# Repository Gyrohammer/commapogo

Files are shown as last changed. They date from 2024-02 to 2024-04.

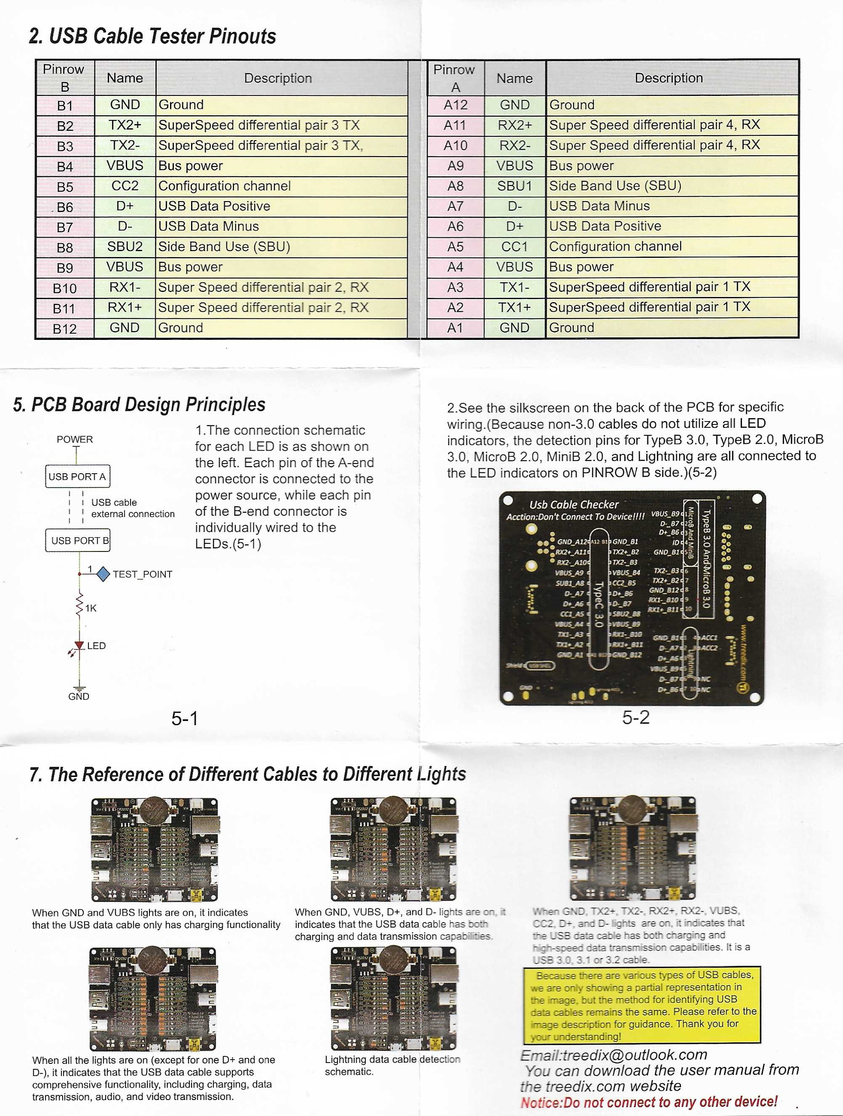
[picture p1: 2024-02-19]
testing_equipment/cable_tester/manual2.jpg

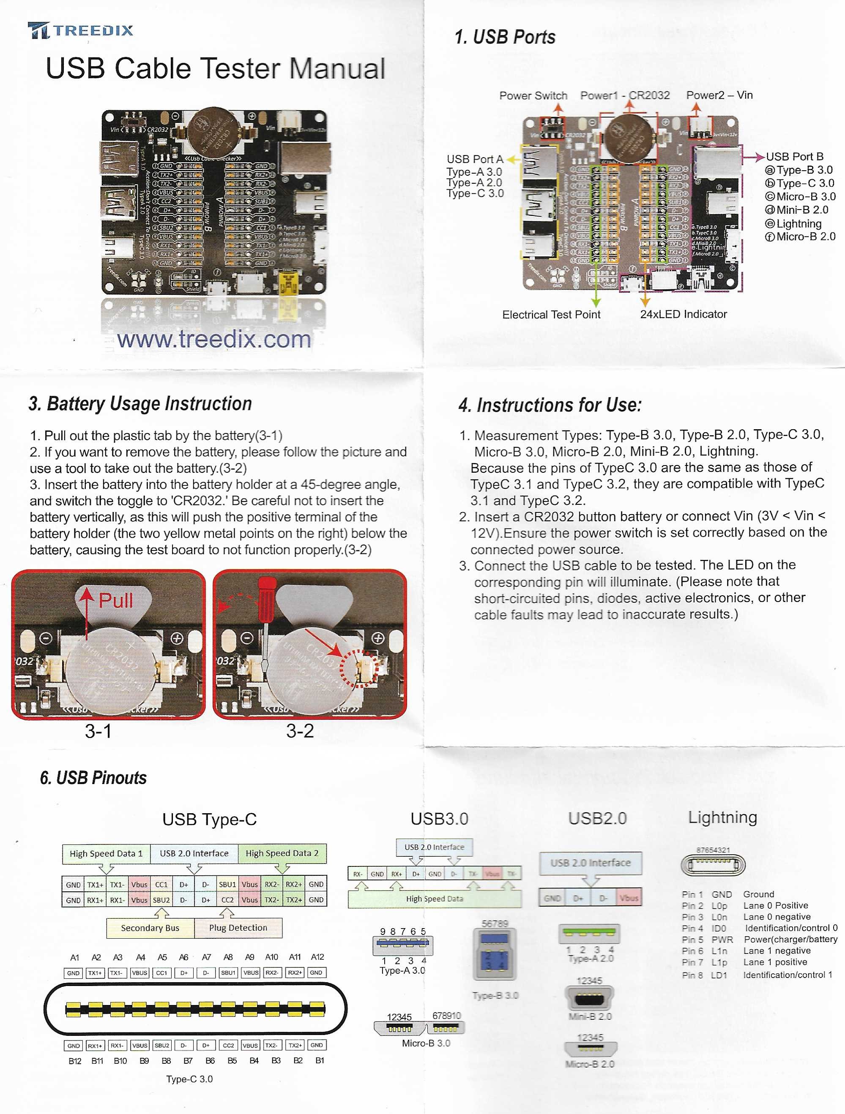
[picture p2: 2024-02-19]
testing_equipment/cable_tester/manual1.jpg

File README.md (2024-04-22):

# CommaPOGO
I recently have come across a project for the Comma3X that utilizes pogo pins for the quick disconnect of a comma3x. This is my attempt to create an open source alternative to that mount that is DIY and 3D printable. I was inspired after seeing the mount that @cloudj0816 made in the [OpenPilot community discord](https://discord.com/invite/avCJxEX). All credit goes to him for this initial idea! If you'd like to purchase one of his connectors (full CNC metal), you can find the wait list in the #hw-unofficial channel. 

## Goals:
- Inexpensive
- Open Source
- 3D Printed
- ~~Angle adjustment (for imperfect mounting positions)~~
    - This is more of a future goal. I'm first going to focus on getting the static mount correct.

## Progress Tracking
### Parts
Preliminary BOM: 
| Colloqiual Name| Part No. | Quantity | 
| --- | --- | --- |
| Pogo Pin  | ~~2906-4-15-20-75-14-11-0~~  | ~~14~~ |
| USB-C Connector | ~~HC005-1A1H1A103-0HR~~ | 2 |
| ASA Filament | n/a | <100g |
| K&J Magnets | D83-N52 | 4 |
|3M Adhesive | 3M™ VHB™ Tape 5952 | ~100mm<sup>2</sup> (~1.5in<sup>2</sup>)|

- [x] Pogo Pins
- [x] USB-C Connector
- [x] Magnets
- [x] Adhesive
#
### Board Development
- [x] General layout
- [x] Trace routing
- [x] Trace power calculations - Data analysis pending (2/15/24)
#### MKI Development
- [x] Initial refinement (MKI)
- [x] Finalization
- [x] Ordered 
- [x] Testing - Failed
- [x] Troubleshooting/diagnosis begins for MKI
- [x] Results finalized, head into next revision.  
#### MKII Development
- [x] Secondary Refinement (MKII)
- [x] Ordered
- [x] Testing - Failed
- [x] Troubleshooting/diagnosis begins for MKII
- [x] Project frozen.
- [ ] Results finalized, head into next (final) revision.
#### MKIII Development
- [ ] Tertiary Refinement (MKIII)
- [ ] Ordered
- [ ] Testing
- [ ] Troubleshooting/diagnosis begins for MKIII
- [ ] Results finalized.

#
### C3X Windshield Mount
- [x] PCB imported and modeled.
- [x] Male mount modeled
- [x] Female mount modeled
- [x] Mock-up mount printed.
- [x] Mount refinement
- [x] Test-bed mounts printed
- [x] Test-beds tested
- [x] 'Gravimatrix' mock-up printed
- [x] Project frozen.
- [ ] 'Gravimatrix' refinement - Minor adjustments being made
- [ ] Preliminary testing
- [ ] Production unit trials
#
### Field Testing
- [ ] Endurance testing (50 hours usage)
- [ ] Vibration testing
- [ ] Heat testing (7 day constant connectivity)
#
## Specifications Pertaining to the Project
- Comma3X Weight: 311g (11oz)
- Power Usage: See the [summary spreadsheet](/power_data/summary.xlsx) for this data.
#
## Separate Updates

### March 10th, 2024
I've gotten the first hand-built boards put together and making a solid connection! The most likely candidate for the mounting system will be the Gravimatrix design, as that is the most solid. But as of 3/10/24 I have a working prototype! Soldering USB-C connectors by hand is extremely difficult, who'da thunk it?

These connectors will likely be soldered on from the manufacturer going forward, this will ensure consistency and quality at the cost of a few cents per board. A compromise I am more than willing to make.

### March 19th, 2024

PCB no worky! I believe I have some crosstalk/interference throughout the coupler. I'll be re-assessing and redesigning the PCB to hopefully counteract this and get a working connection.

### March 21st, 2024

This weekend I'll be using an oscilloscope to check signal integrity. Hopefully its simple as that, and adding a ground plane(s) will solve it. I had no idea what a ground-plane was until I asked for ideas/advice on the electrical engineering stack exchange. [Heres the thread where that was suggested!](https://electronics.stackexchange.com/questions/706633/usb-c-pogo-pin-coupler-troubleshooting).

### April 10th, 2024

Oscilloscope readings showed little to no interference. Messages were coming and going normally, with solid definition. The second PCB design has run into the same error, in the same way. I will be doing some more testing including soldering wires directly from pad-to-pad in an attempt to isolate this to one component. If that doesnt work, I'll be doing one final re-design before putting this project on hold for a while.

### April 18th, 2024
I finally got around to wiring the pads directly to one another for testing! Bad news is that it still doesnt work. I'm unsure, at this point, why this board doesnt work correctly. I feel as if I'm getting some sort of cross-talk between the connections. I'll be tring one more configuration, flipped, to see if that yields any other results. If this doesnt work then I have a backup plan which involves some consumer-hardware and a 3D printed case to house it. I'm hoping this custom solution works, as I put a lot of time into it, but if not then it is what it is. I should've gotten an EE degree, physics is useless here! Actually it was useful for the magnet force calculations.

### April 22nd, 2024
Unfortunately it seems that I've hit the limit of my knowledge/ability with this project. I cannot get the communication to work correctly across the interlink. I have already spend about $400 in material on this project, putting together another PCB for order would only add to that and would likely not work. Not to mention the hours spent testing and designing the mounts/PCB revisions. This was still an excellent journey to go on! Maybe one day I'll revisit it. This repo does contain some useful info, though, such as power statistics and the weight of the unit, hopefully that will be useful to someone should they stumble across this.

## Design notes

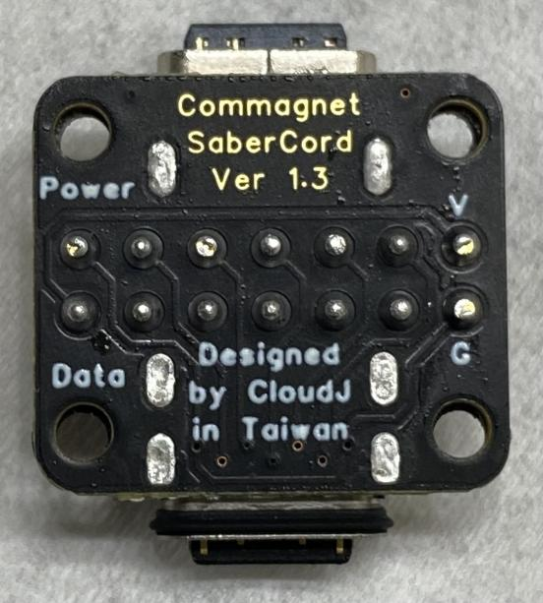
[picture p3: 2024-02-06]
sabercord_reference/PCB_Layout.webp

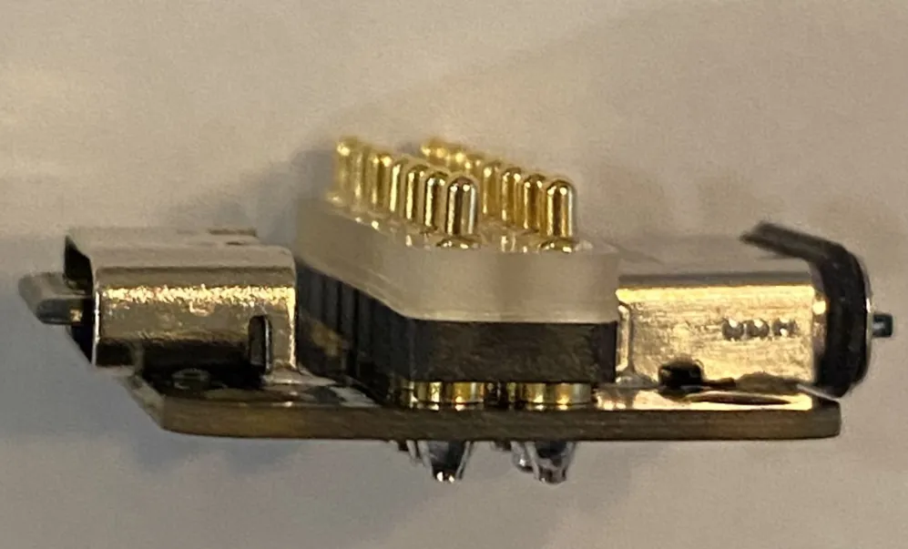
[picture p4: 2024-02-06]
sabercord_reference/side_shot.webp

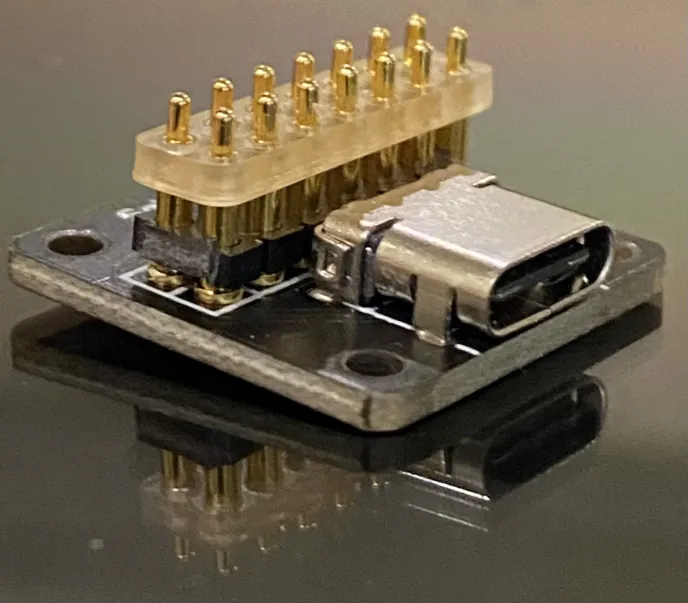
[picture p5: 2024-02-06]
sabercord_reference/aboce_shot.webp

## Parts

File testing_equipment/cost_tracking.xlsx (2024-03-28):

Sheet: Project Overall
Item | Description | Cost | Date | Total | Breakeven Units | Project Length (days) | Cost/Day
Digikey 1 | Pogo pins and USB-C connectors | $33.90 | 2024-02-15 | $342.71 | 7 | 41 | $8.36
K&J Magnets | Misc magnet testing | $55.00 | 2024-02-15
PCBWay 1 | Initial pcb order | $19.24 | 2024-02-17
PCBWay 2 | Second pcb order assembled | $42.80 | 2024-03-06
JLCPCB 1 | First assembled order, failed in prod | $5.15 | 2024-03-07
JLCPCB 2 | Second assembled order, useless | $50.25 | 2024-03-11
Digikey 2 | Pogo pins and pogo pins | $59.70 | 2024-03-12
JLCPCB 3 | Third assembled order, pending | $54.49 | 2024-03-27
K&J Magnets | Final magnet testing | $22.18 | 2024-03-27

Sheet: Per Unit
Component | Price/unit | Quantity | Total | Raw Cost
Pogo Pins | $0.64 | 14 | $8.97 | $40.01
PCB | $12.00 | 2 | $24.00
Magnets | $1.71 | 4 | $6.84
ASA | $25.00 | 0.008 | $0.20

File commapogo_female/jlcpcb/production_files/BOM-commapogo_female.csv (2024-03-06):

Comment | Designator | Footprint | LCSC
Conn_02x12_Row_Letter_Last | J2 | USB-C-SMD_HC005-1A1H1A103-0HR | C2894904

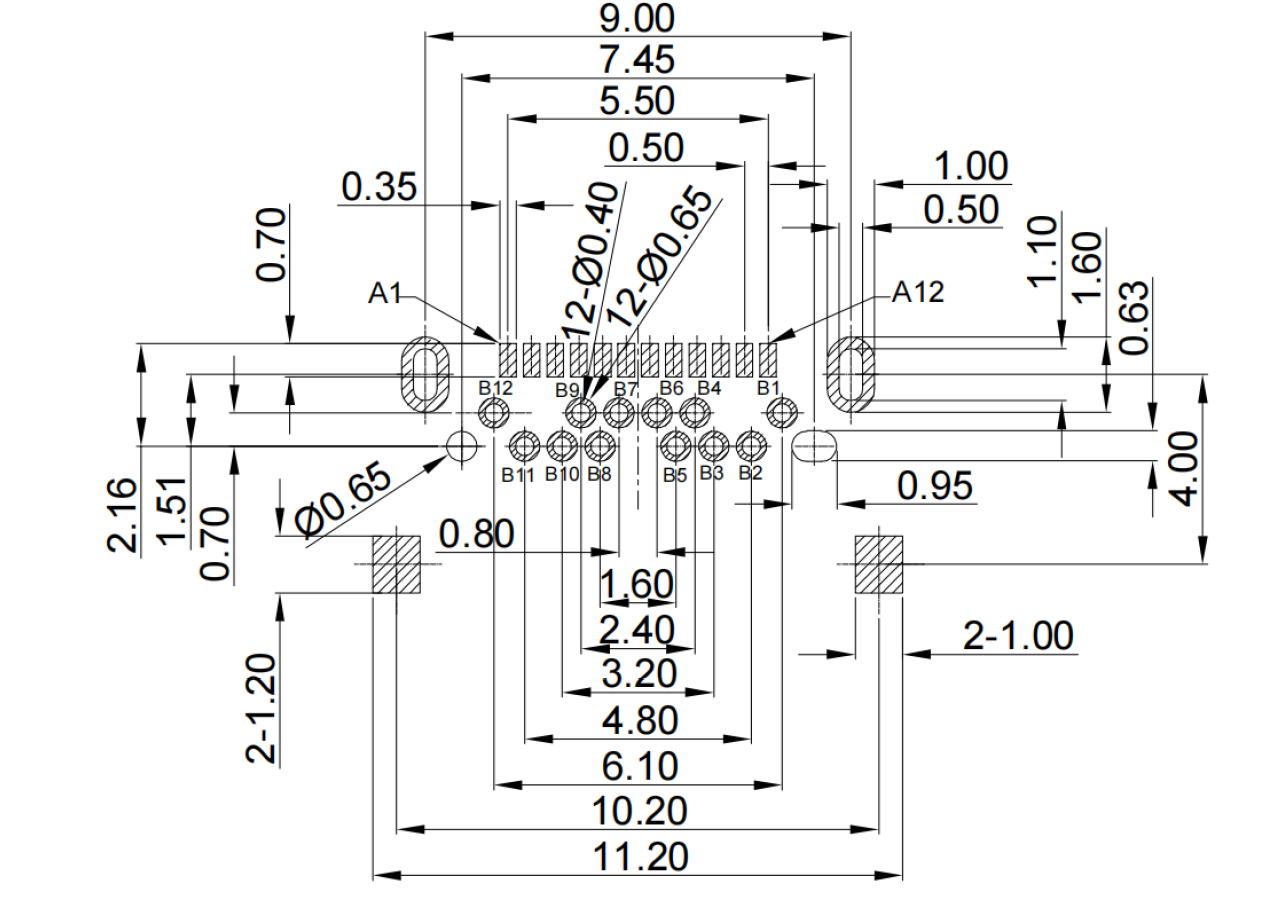
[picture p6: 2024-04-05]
component_data/usb_connector/GT-USB-7001C/GT-USB-7001C.png

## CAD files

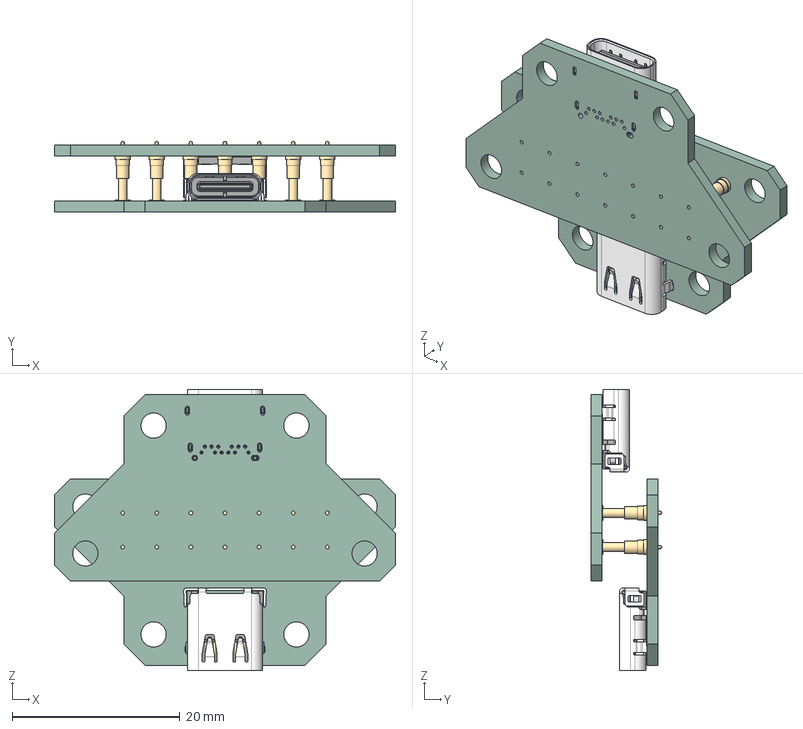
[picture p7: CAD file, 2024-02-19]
3d files/baseline_model/baseline_PCB.step
40.6 x 8.41 x 33.5 mm
PogoPads x 14
SaberCord_Copy_Male PCB x 2

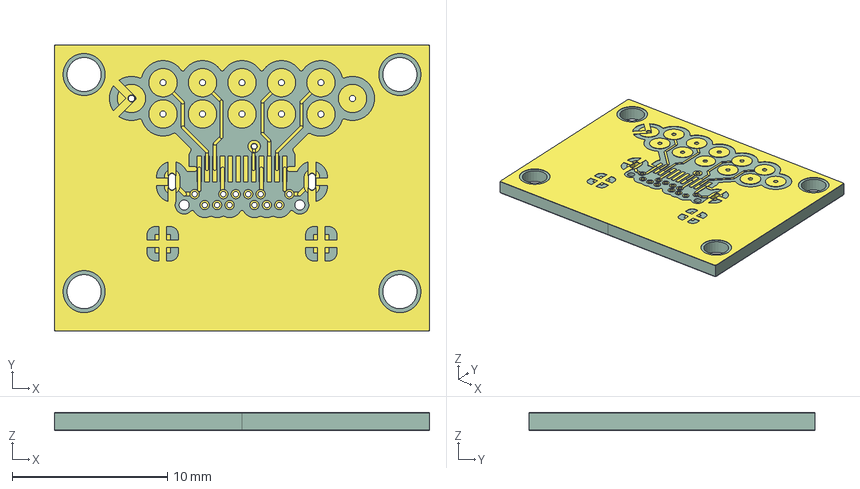
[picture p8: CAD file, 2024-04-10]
3d files/commaPOGO.step
24.1 x 18.4 x 1.16 mm
commapogo_male_track_1
commapogo_male_track_2
commapogo_male_track_3
commapogo_male_track_4
commapogo_male_track_5
commapogo_male_track_6
commapogo_male_track_7
commapogo_male_track_8
commapogo_male_track_9
commapogo_male_track_10
commapogo_male_track_11
commapogo_male_track_12
commapogo_male_track_13
commapogo_male_track_14
commapogo_male_track_15
commapogo_male_track_16
commapogo_male_track_17
commapogo_male_track_18
commapogo_male_track_19
commapogo_male_track_20
commapogo_male_track_21
commapogo_male_track_22
commapogo_male_track_23
commapogo_male_track_24
commapogo_male_track_25
commapogo_male_track_26
commapogo_male_track_27
commapogo_male_track_28
commapogo_male_track_29
commapogo_male_track_30
commapogo_male_track_31
commapogo_male_track_32
commapogo_male_track_33
commapogo_male_zone_1
commapogo_male_zone_2
commapogo_male_pad_1
commapogo_male_pad_2
commapogo_male_pad_3
commapogo_male_pad_4
commapogo_male_pad_5
commapogo_male_pad_6
commapogo_male_pad_7
commapogo_male_pad_8
commapogo_male_pad_9
commapogo_male_pad_10
commapogo_male_pad_11
commapogo_male_pad_12
commapogo_male_pad_13
commapogo_male_pad_14
commapogo_male_pad_15
commapogo_male_pad_16
commapogo_male_pad_17
commapogo_male_pad_18
commapogo_male_pad_19
commapogo_male_pad_20
commapogo_male_pad_21
commapogo_male_pad_22
commapogo_male_pad_23
commapogo_male_pad_24
commapogo_male_pad_25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

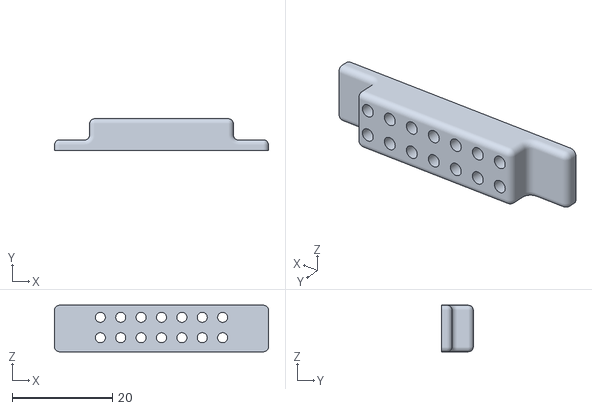
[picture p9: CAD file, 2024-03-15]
3d files/pogo_jigs/pogo_pin_jig_2p000_thick.stl
42.7 x 6.30 x 9.28

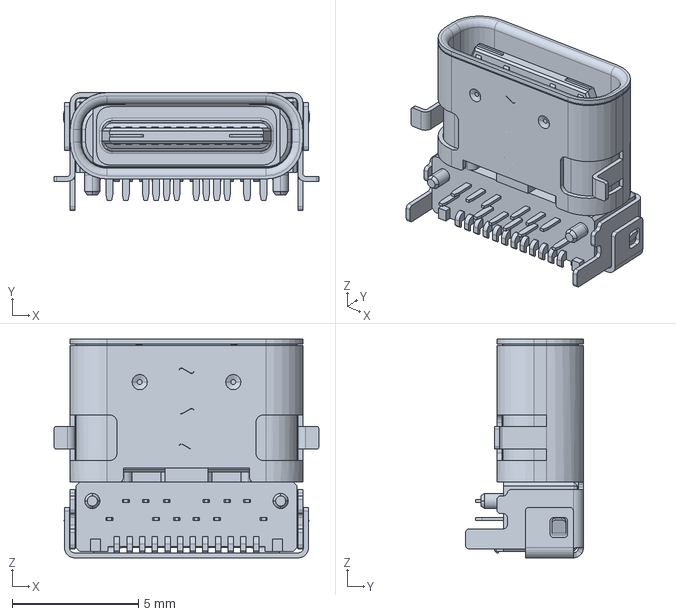
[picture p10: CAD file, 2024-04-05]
3d files/pre-fab_parts/GT-USB-7001C.stp
10.5 x 4.66 x 8.65 mm

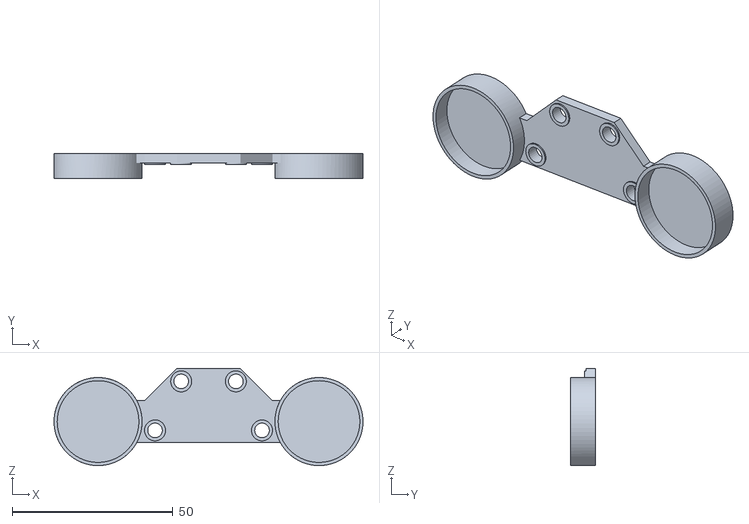
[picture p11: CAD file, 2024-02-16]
3d files/prototype_Gravimatrix/gravimatrix_d73/windshield_side.stl
96.1 x 7.66 x 30.2

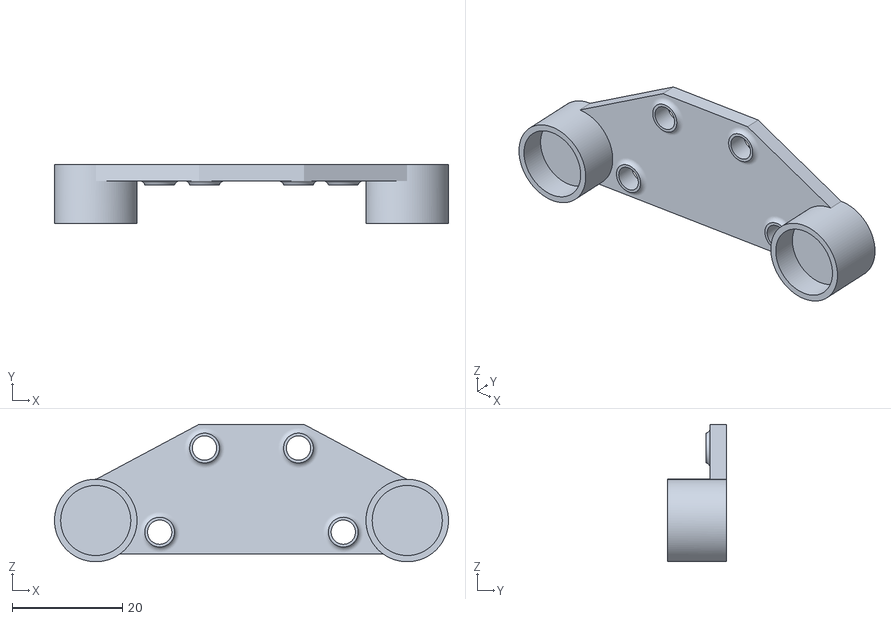
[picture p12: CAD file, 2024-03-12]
3d files/prototype_Gravimatrix/gravimatrix_d83/windshield_side_v2.stl
71.4 x 10.8 x 24.9

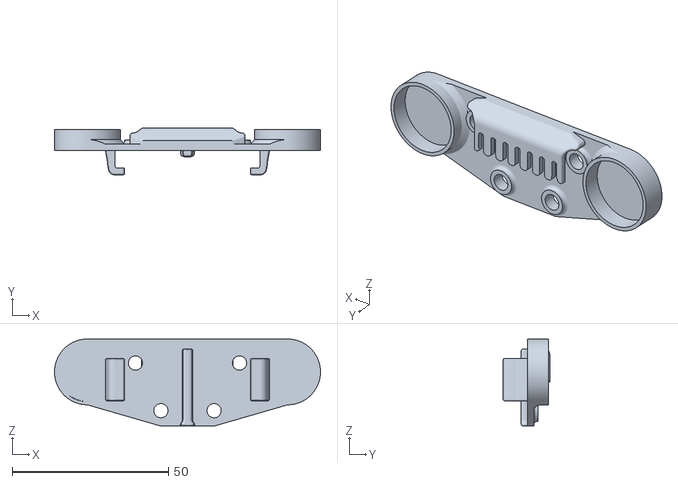
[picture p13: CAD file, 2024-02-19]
3d files/prototype_Gravimatrix/gravimatrix_dc3/unit_side.stl
85.1 x 15.0 x 27.8

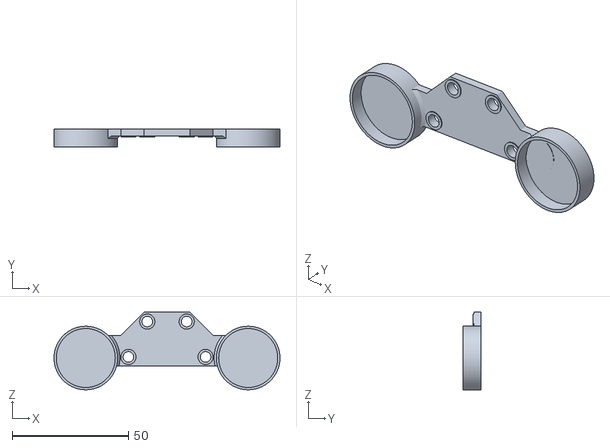
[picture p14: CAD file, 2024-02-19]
3d files/prototype_Gravimatrix/gravimatrix_dx03/windshield_side.stl
97.4 x 7.65 x 33.4

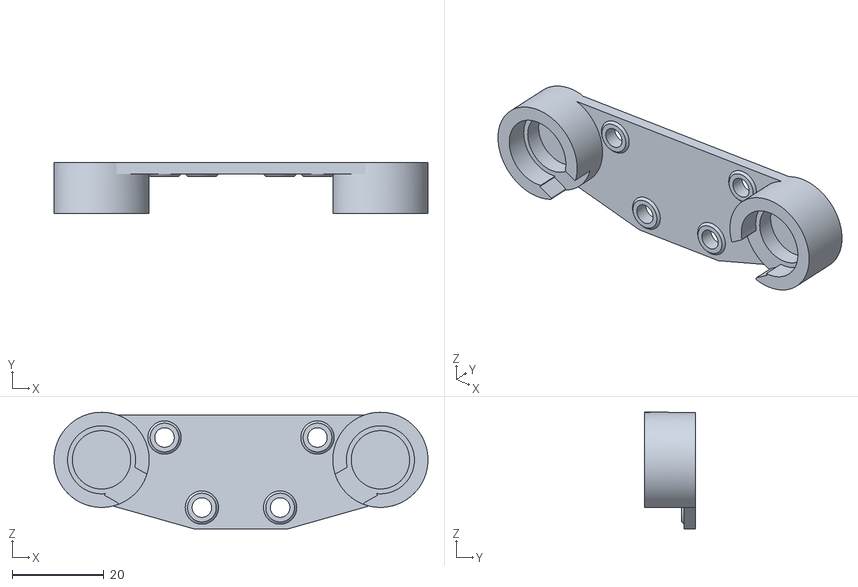
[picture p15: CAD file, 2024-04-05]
3d files/prototype_Gravimatrix/windshield_side_slotted.stl
81.4 x 11.0 x 25.3

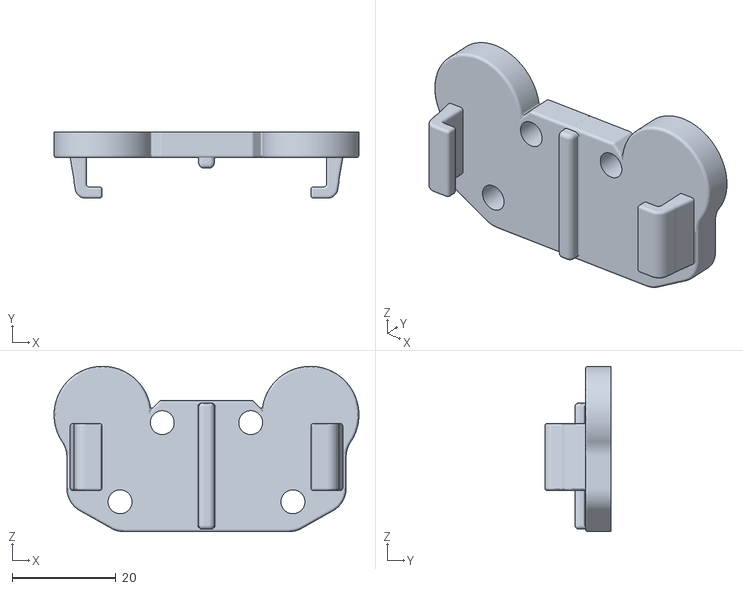
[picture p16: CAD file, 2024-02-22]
3d files/prototype_polaron/unit mount.stl
58.7 x 12.8 x 31.8

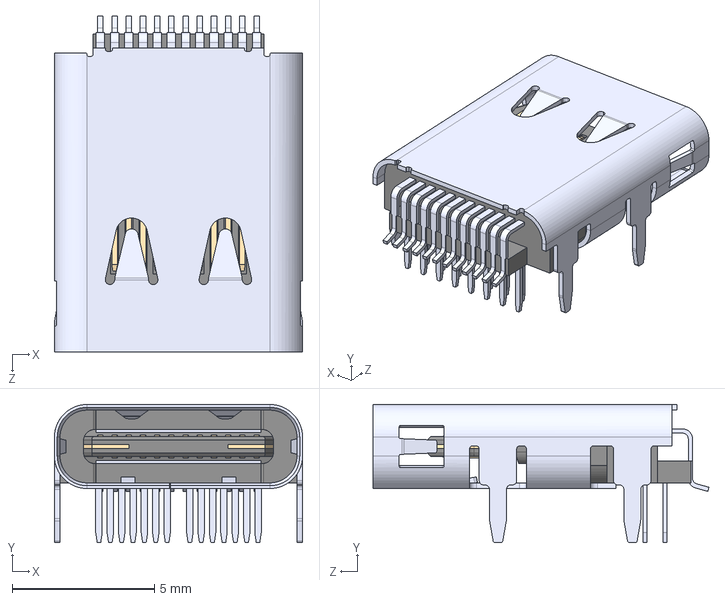
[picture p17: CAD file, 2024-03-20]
component_data/usb_connector/SS_52400_003/SS-52400-003.step
8.74 x 4.86 x 11.8 mm

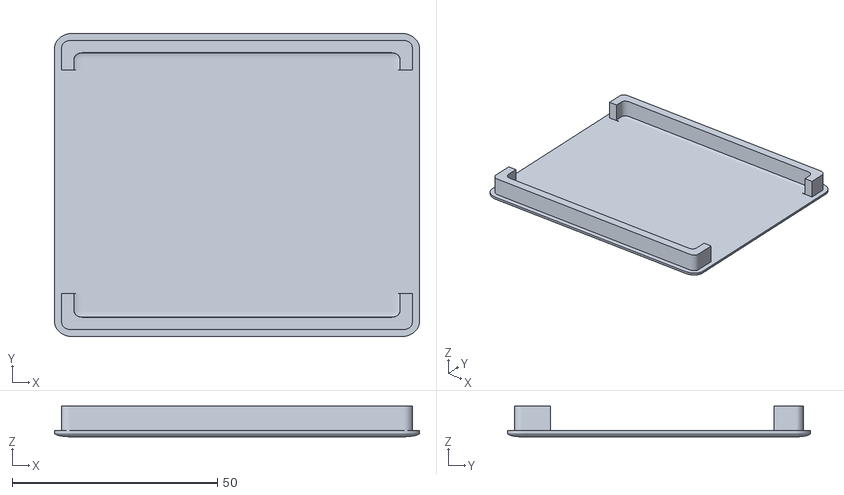
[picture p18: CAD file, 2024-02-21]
testing_equipment/cable_tester/usb3cablecheckdeckel.stl
89.0 x 74.0 x 7.50

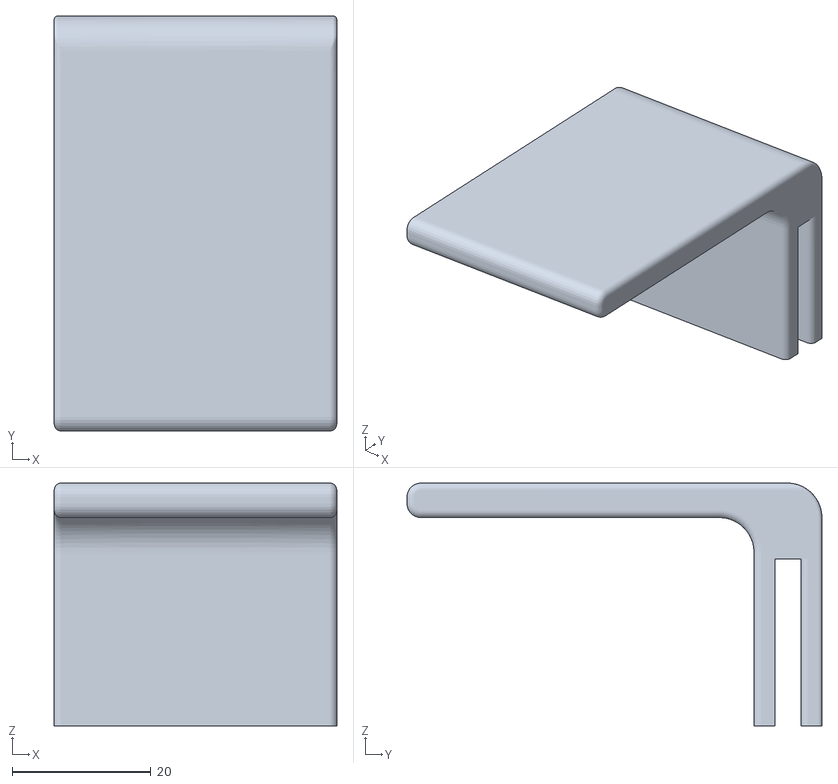
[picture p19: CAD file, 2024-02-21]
testing_equipment/mount_shock_test.stl
40.7 x 59.8 x 35.0

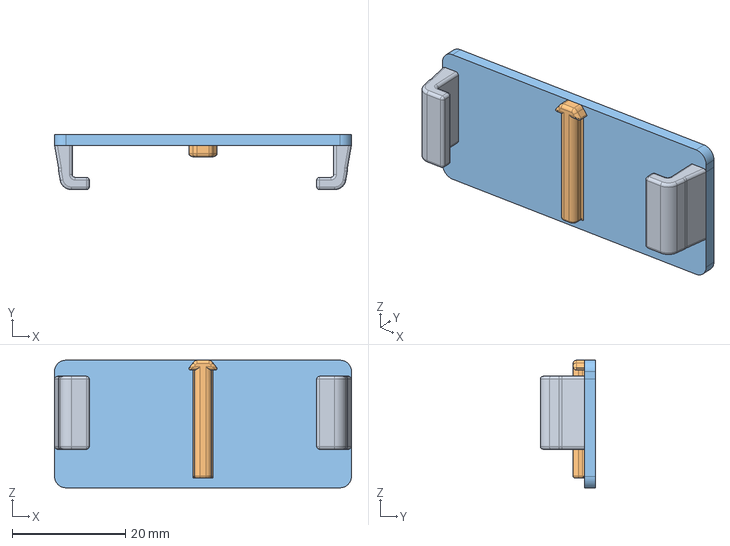
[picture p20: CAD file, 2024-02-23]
3d files/comma3x_windshield_mount.step
52.5 x 9.80 x 22.6 mm

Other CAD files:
3d files/pogo_jigs/pogo_pin_jig_1p800_thick.stl
3d files/pre-fab_parts/2906-4-15-20-75-14-11-0.step
3d files/prototype_Gravimatrix/gravimatrix_d73/unit_side.stl
3d files/baseline_model/baseline_PCB.dwg
3d files/baseline_model/baseline_pcb_only.f3z
3d files/comma3x_windshield_mount.dwg
3d files/comma3x_windshield_mount.f3d
3d files/pogo_jigs/pogo_pin_jig_0p07.stl
3d files/pogo_jigs/pogo_pin_jig_0p125.stl
3d files/pogo_jigs/pogo_pin_jig_1p250.stl
3d files/pogo_jigs/pogo_pin_jig_1p350.stl
3d files/pogo_jigs/pogo_pin_jig_1p400.stl
3d files/pogo_jigs/pogo_pin_jig_1p400_framed.stl
3d files/pogo_jigs/pogo_pin_jig_1p400_thick.stl
3d files/pogo_jigs/pogo_pin_jig_1p400_thin.stl
3d files/pogo_jigs/pogo_pin_jig_1p50offset.stl
3d files/pogo_jigs/pogo_pin_jig_1p50offset_thick.stl
3d files/pogo_jigs/pogo_pin_jig_1p600_thick.stl
3d files/pogo_jigs/pogo_pin_jig_1p640_thick.step
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

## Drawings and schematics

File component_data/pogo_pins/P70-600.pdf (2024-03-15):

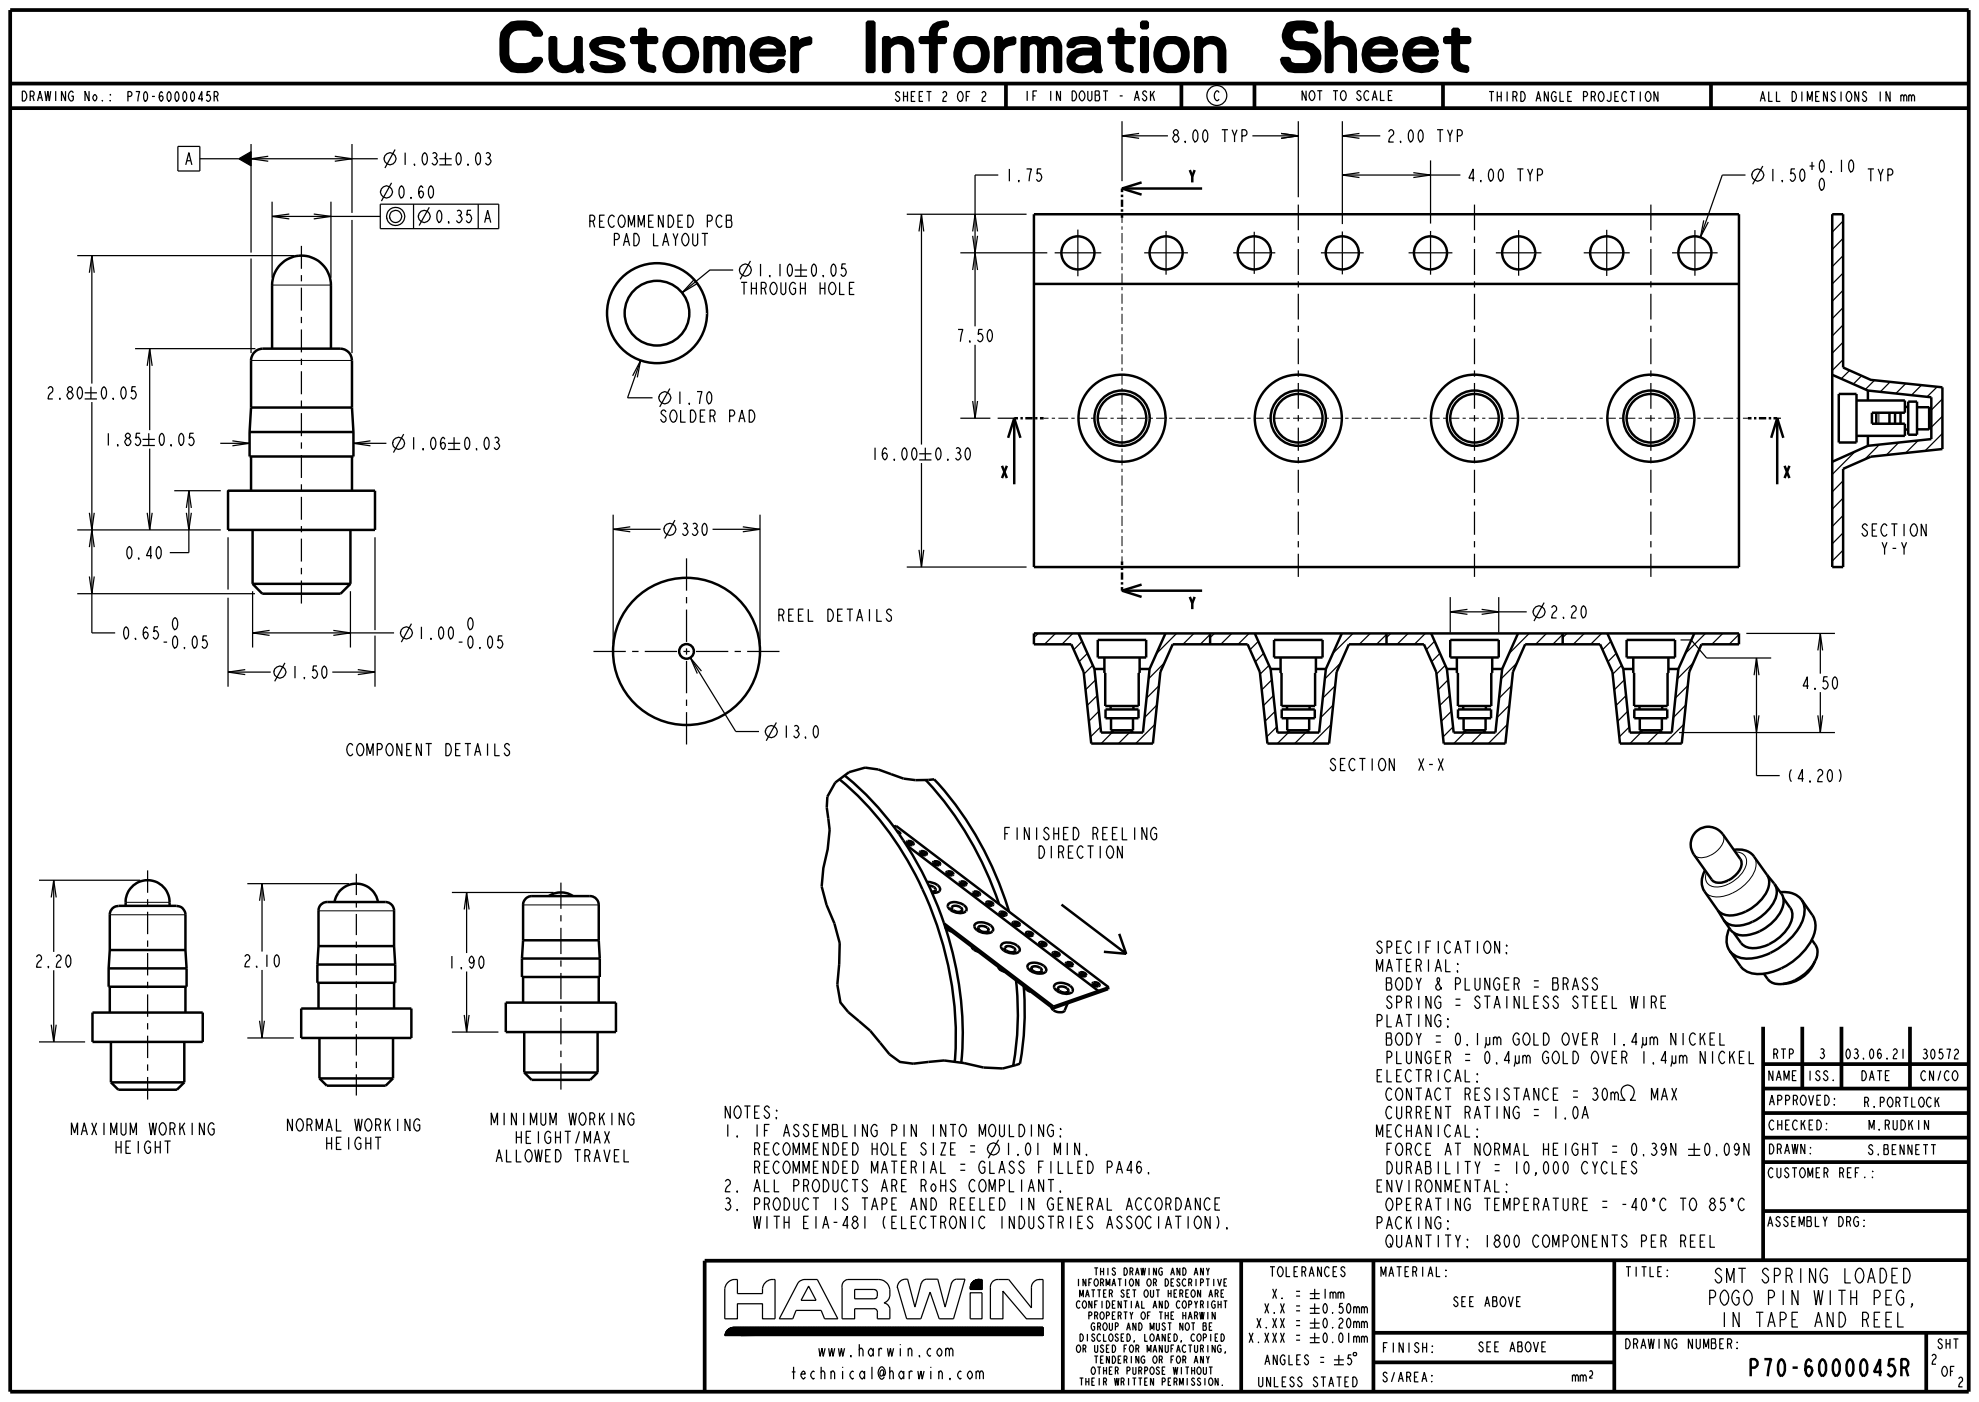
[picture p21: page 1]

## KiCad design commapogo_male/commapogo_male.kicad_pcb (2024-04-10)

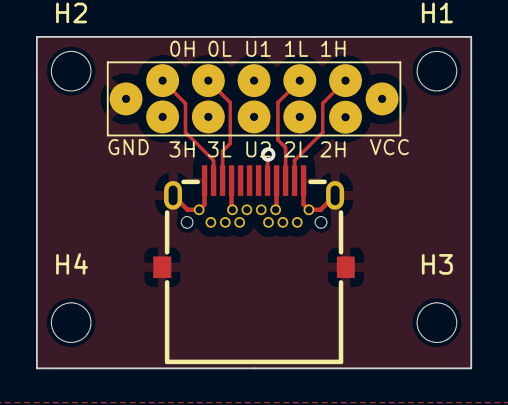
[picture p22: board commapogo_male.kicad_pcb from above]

Board: 4 copper layers, 24.1 x 18.4 mm, 6 parts (0 on the bottom side), 12 nets.

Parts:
H1, H2, H3, H4: MountingHole; MountingHole_2.2mm_M2
J1: Conn_02x07_Row_Letter_Last; 2x7_Pogo_Male
J2: Conn_02x12_Row_Letter_Last; GT-USB-7001C

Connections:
+12V: J1.14 (Pin_7b), J2.A4 (Pin_4a), J2.A9, J2.B4 (Pin_4b), J2.B9 (Pin_9b)
/CAN0_N: J1.3 (Pin_3a), J2.A3 (Pin_3a)
/CAN0_P: J1.2 (Pin_2a), J2.A2 (Pin_2a)
/CAN1_N: J1.5 (Pin_5a), J2.A10 (Pin_10a)
/CAN1_P: J1.6 (Pin_6a), J2.A11 (Pin_11a)
/CAN2_N: J1.12 (Pin_5b), J2.B3 (Pin_3b)
/CAN2_P: J1.13 (Pin_6b), J2.B2 (Pin_2b)
/CAN3_N: J1.10 (Pin_3b), J2.B10 (Pin_10b)
/CAN3_P: J1.9 (Pin_2b), J2.B11 (Pin_11b)
/SBU1: J1.4 (Pin_4a), J2.A8 (Pin_8a)
/SBU2: J1.11 (Pin_4b), J2.B8 (Pin_8b)
GND: J1.1 (Pin_1a), J2.0, J2.A1 (Pin_1a), J2.A12 (Pin_12a), J2.B1, J2.B12 (Pin_12b)

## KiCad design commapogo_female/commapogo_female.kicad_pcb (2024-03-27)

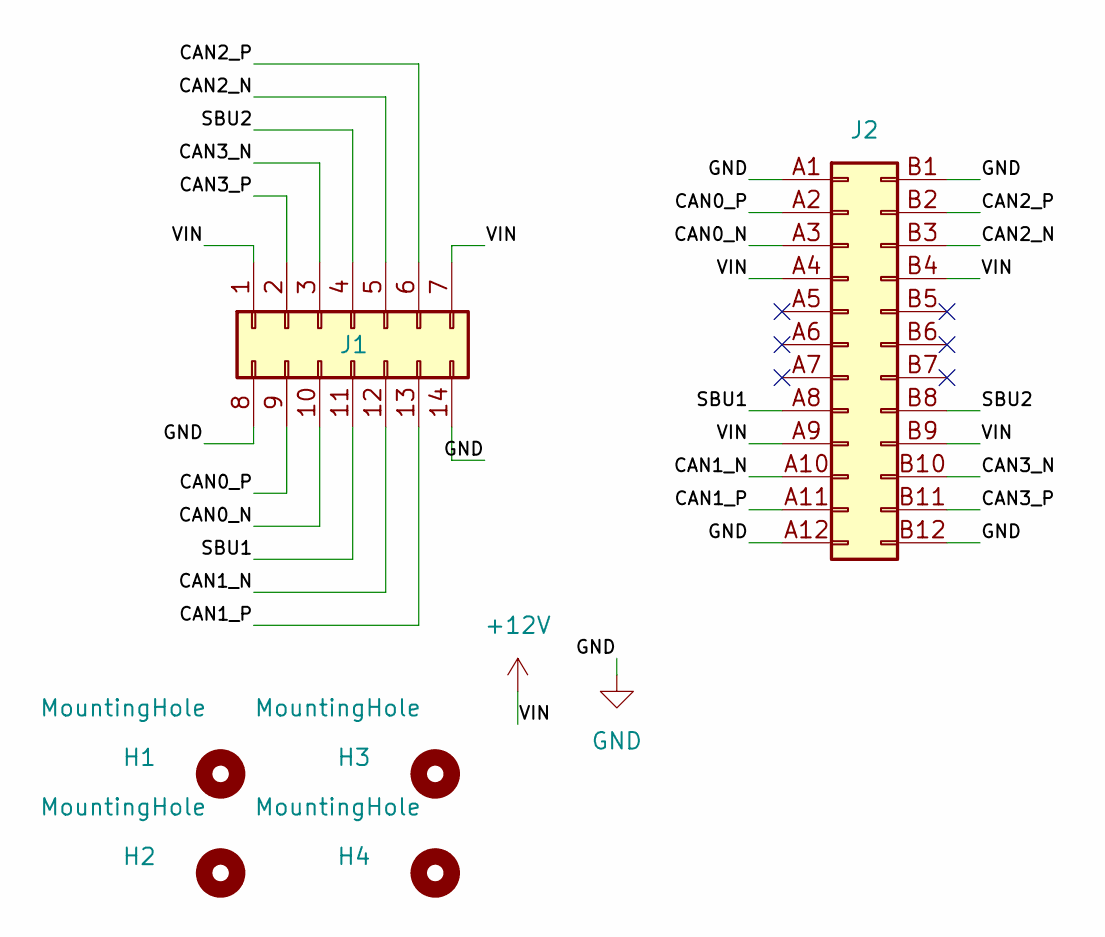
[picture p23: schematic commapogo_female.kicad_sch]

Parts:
H1, H2, H3, H4: MountingHole; MountingHole_3mm
J1: Conn_02x07_Row_Letter_Last; 2x7_Pogo_Male
J2: Conn_02x12_Row_Letter_Last; USB-C-SMD_HC005-1A1H1A103-0HR; LCSC C2894904

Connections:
+12V: J1.1 (Pin_1a), J1.7 (Pin_7a), J2.A4 (Pin_4a), J2.A9, J2.B4 (Pin_4b), J2.B9 (Pin_9b)
/CAN0_N: J1.10 (Pin_3b), J2.A3 (Pin_3a)
/CAN0_P: J1.9 (Pin_2b), J2.A2 (Pin_2a)
/CAN1_N: J1.12 (Pin_5b), J2.A10 (Pin_10a)
/CAN1_P: J1.13 (Pin_6b), J2.A11 (Pin_11a)
/CAN2_N: J1.5 (Pin_5a), J2.B3 (Pin_3b)
/CAN2_P: J1.6 (Pin_6a), J2.B2 (Pin_2b)
/CAN3_N: J1.3 (Pin_3a), J2.B10 (Pin_10b)
/CAN3_P: J1.2 (Pin_2a), J2.B11 (Pin_11b)
/SBU1: J1.11 (Pin_4b), J2.A8 (Pin_8a)
/SBU2: J1.4 (Pin_4a), J2.B8 (Pin_8b)
GND: J1.8 (Pin_1b), J1.14 (Pin_7b), J2.1, J2.2, J2.3, J2.4, J2.A1 (Pin_1a), J2.A12 (Pin_12a), J2.B1, J2.B12 (Pin_12b)

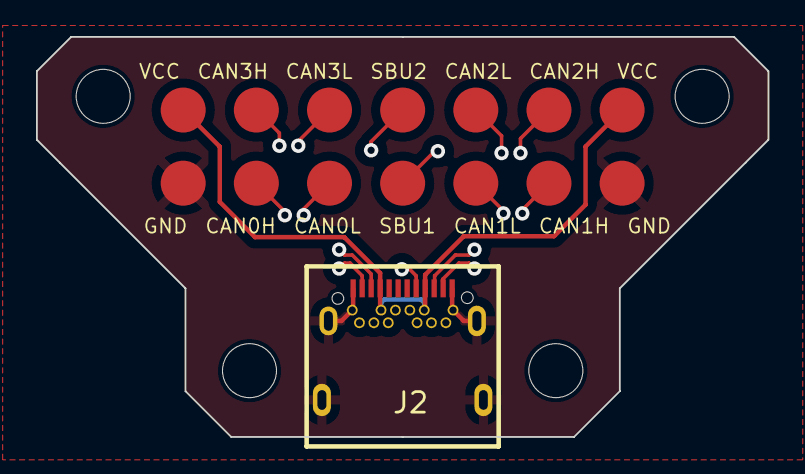
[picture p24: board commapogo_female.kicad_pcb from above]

Board: 4 copper layers, 40.6 x 22.2 mm, 6 parts (0 on the bottom side), 12 nets.

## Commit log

2024-02-06 add pcb files for initial commit
    [SaberCord_Copy.kicad_pcb]
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2024-02-06 add visual reference and update pcb schema
    [SaberCord_Copy.kicad_sch]
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2024-02-06 finish wiring schematic for pogo
    [SaberCord_Copy.kicad_sch]
2024-02-07 refine footprint and schema
    [SaberCord_Copy.kicad_pcb, SaberCord_Copy.kicad_sch]
2024-02-07 add excel parts tracking list
    [parts_list.xlsx]
2024-02-07 refine pcb add mount holes create model
    [SaberCord_Copy.step]
2024-02-07 mock up connector in f360
    [USB4056-03-A_REVA2.step, parts_list.xlsx]
2024-02-08 organize files into parts
    [Connector_Male_v1 v5.f3z, SaberCord_Copy.step, SaberCord_Copy_Female.kicad_pcb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]
2024-02-08 update parts list with alternatives
    [SaberCord_Copy_Male.kicad_pcb, SaberCord_Copy_Male.step, parts_list.xlsx]
2024-02-09 add more formats of mount files
    [Mount_Design v2.dwg, Mount_Design v2.step, Mount_Design.f3z]
2024-02-09 flipped connector again, still incorrect fix later
    [SaberCord_Copy_Male.kicad_pcb]
2024-02-12 fusion360 possible, additional files added
    [SaberCord_Copy_Female.kicad_pcb, SaberCord_Copy_Female.kicad_sch]
2024-02-12 fixed female connector mirror
    [SaberCord_Copy_Female.kicad_pcb, SaberCord_Copy_Female.kicad_sch]
2024-02-12 implement silkscreen for debug
    [SaberCord_Copy_Female.kicad_pcb, SaberCord_Copy_Male.kicad_pcb]
2024-02-13 add power data from first run
    [20240212213025944.csv, 20240212213025944.xlsx]
2024-02-13 fix csv formatting
    [20240212213025944.csv]
2024-02-13 fix csv formatting AGAIN
    [20240212213025944.csv, 20240212213025944.xlsx]
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2024-02-13 update printable files and parts list
    [Lower.stl, Upper.stl, parts_list.xlsx]
2024-02-14 organize file systems, redo pcb
    [3X_mount.stl, D73-N52_magnet.STEP, Lower.stl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]
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2024-02-14 export v1 of unit side mount
    [unit_side.stl]
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2024-02-14 add force calculations add prototype parts
    [fitment_peg_magnet.stl, fitment_peg_pcb.stl, force_calculations.xlsx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]
2024-02-14 add another magnet to force calc
    [force_calculations.xlsx]
2024-02-15 upload more power data
    [20240212213025944.csv, 20240214075031963.csv, 20240214075031963.xlsx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]
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2024-02-15 format power data, more analysis
    [20240212213025944.xlsx, 20240214075031963.xlsx, 20240214164119464.xlsx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]
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2024-02-15 continue data analysis, add summary sheet
    [20240215080020564.csv, onboard_45min.xlsx, summary.xlsx]
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2024-02-15 pcb finalized, very exciting
    [SaberCord_Copy_Male.kicad_pcb, female_connector.kicad_pcb, force_calculations.xlsx]
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2024-02-15 begin gerber file creation add pogo alternatives
    Pogo pin alternatives were selected for more robust connections. All
    alternatives will be considered with the most likely candidate pushed to
    the readme.
    Gerber file generation has been started, initial files have been made.
    Other parameters will be determined later.
    [SaberCord_Copy_Male-B_Cu.gbr, SaberCord_Copy_Male-B_Mask.gbr, SaberCord_Copy_Male-B_Paste.gbr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]
2024-02-15 calculations continued
    Safety factor calculations revised and updated.
    [SaberCord_Copy_Male.kicad_pcb, force_calculations.xlsx]
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2024-02-15 convert xlsx to csv
    [20240215152916505.csv]
2024-02-16 multi magnet versions exported to printable files
    four magnet sizes have been chosen for testing purposes. Their models
    and corresponding mounts have been categorized for printing and testing.
    [D73-N52.STEP, D83-N52.STEP, DC3-N52.STEP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]
2024-02-16 generate gerber files for production
    Orders have been submitted to manufacturer for evaluation.
    [SaberCord_Copy_Male-B_Cu.gbr, SaberCord_Copy_Male-B_Mask.gbr, SaberCord_Copy_Male-B_Paste.gbr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]
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2024-02-16 re-arrange files and folders, update components
    [2906-4-15-20-75-14-11-0.step, D73-N52_magnet.STEP, commaPOGO.step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]
2024-02-16 correct description of cloudj connector
2024-02-19 reworked models added testing jig
    All test-bed modules have been reworked to be more 'printer friendly'.
    Print 90deg on the flat side of the unit_side connector for easier
    printing. Still a difficult print, but a tad less so.
    Testing jig has been added for magnet strength. This will be heavily
    revised this is only for light initial shock testing.
    [baseline_PCB.dwg, baseline_PCB.step, baseline_pcb_only.f3z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]
2024-02-19 update parts list with bom and other pricing
    [parts_list.xlsx]
2024-02-19 increased female smd pad size for slop
    [female_connector.kicad_pcb]
2024-02-19 update testing and force calculations
    [force_calculations.xlsx, summary.xlsx]
2024-02-20 added quick final files before home
    [parts_list.xlsx]
2024-02-21 add new prototype, edit misc excel
    [force_calculations.xlsx, mount_shock_test.stl, summary.xlsx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]
2024-02-21 modified polaron prototype unit mount
    [mount unit.stl]
2024-02-22 update polaron mount
    polaron mount continues to recieve updates, next steps will be testing
    with the actual pcb when it gets to the US
    [unit mount.stl, windshield mount .stl]
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2024-02-22 corrected magnet type in parts list
    [parts_list.xlsx]
2024-02-23 add windshield models and other misc models
    [comma3x_windshield_mount.dwg, comma3x_windshield_mount.f3d, comma3x_windshield_mount.step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]
2024-02-23 add reworked polaron unit mount stl
    [unit mount.stl]
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2024-03-05 rev2 of boards plus compliant bom
    The female connector has been updated with larger pads for better slop
    compensation.
    A BOM matching the PCBWay format has been implemented for each part to
    aid in manufacturing/assembly.
    [SaberCord_Copy_Male-B_Cu.gbr, SaberCord_Copy_Male-B_Mask.gbr, SaberCord_Copy_Male-B_Paste.gbr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]
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2024-03-06 change usb c connector export to jlcpcb
    [BOM-SaberCord_Copy_Male.csv, BOM-female_connector.csv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]
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2024-03-06 adjust file trees and clean up
    [BOM-commapogo_fem.csv, BOM-commapogo_male.csv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]
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2024-03-08 change file naming move to archive
    [BOM-commapogo_female.csv, c3x_fem_BOM.xlsx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]
2024-03-10 rework usb-c footprint for jlcpcb
    [BOM-female_connector.csv, c3x_fem_BOM.xlsx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]
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2024-03-11 add more 3d models to correct directory
    This includes multiple pogo pin guides with differing tolerance values,
    .25, .125, and .07 (flush)
    Gravimatrix prototype has also been updated with some minor changes
    [pogo_pin_jig_0p07offset.stl, pogo_pin_jig_0p125offset.stl, pogo_pin_jig_1p250offset.stl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]
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2024-03-12 add additional pogo jigs
    [pogo_pin_jig_1p350offset.stl, pogo_pin_jig_1p40offset.stl, pogo_pin_jig_1p40offset_pressured.stl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]
2024-03-13 sort pogo pin jigs into subdirectory
    [pogo_pin_jig_0p07.stl, pogo_pin_jig_0p125.stl, pogo_pin_jig_1p250.stl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]
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2024-03-14 add more pogo jigs to relevant folder
    [pogo_pin_jig_1p800_thick.stl, pogo_pin_jig_1p850_thick.stl, pogo_pin_jig_1p900_thick.stl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]
2024-03-15 add shorter variant for x-2-x pins
    [unit_side_short.stl, windshield_side_short.stl]
2024-03-15 attach legs to unit side of mount
    [unit_side_short.stl]
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2024-03-21 rework pcb design
    [BOM-commapogo_female.csv, c3x_fem_BOM.xlsx, c3x_male_BOM.xlsx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]
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2024-03-21 upload test jig rework
    [Lower.stl, Upper.stl]
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
